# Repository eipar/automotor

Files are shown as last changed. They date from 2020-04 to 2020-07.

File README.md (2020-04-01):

# automotor
\simple Car's Radiator Driver Control

This is a project for the elective subject "Electronics in the Automotive" of the Electronic Engineering Degree at Universidad Tecnológica Nacional Facultad Regional Buenos Aires (UTN-FRBA).

The purpose of the code is to control the radiator of a car, according to the its temperature. This is done with fuzzy logic in a 8051 8-bit microcontroller.
The temperature and any other alarms is communicated through LIN and CAN protocol, this is done with a LPC1769 Stick.

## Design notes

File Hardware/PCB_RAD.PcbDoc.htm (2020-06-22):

Reporting Options

# File in Previous Format

Date | : | 27/04/2020
Time | : | 20:16:34
Filename | : | C:\Users\Euge\Documents\GitHub\automotor\Hardware\PCB_RAD.PcbDoc

Version | Warning

This file was generated by an earlier version of the software

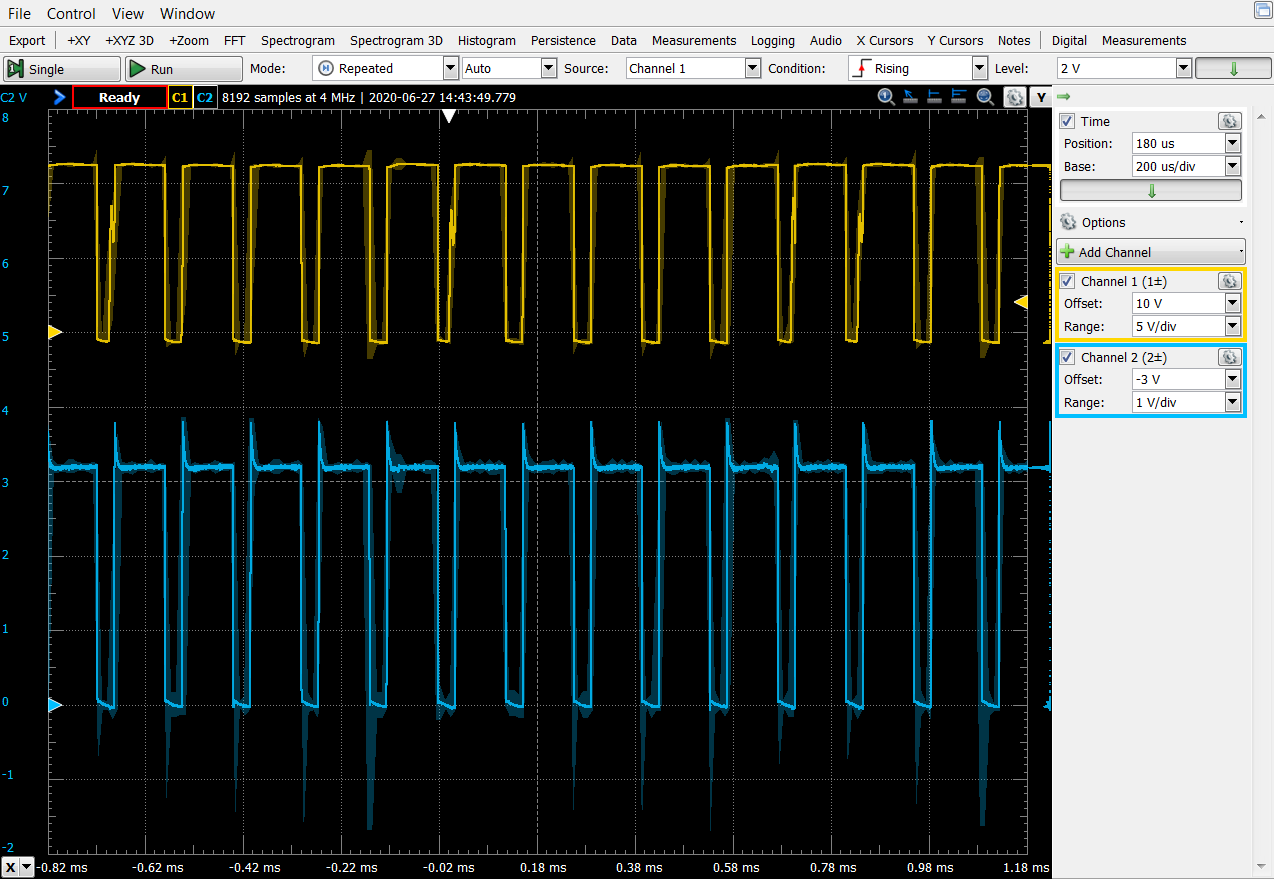
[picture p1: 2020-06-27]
Documentation/Motor/V_PWM.png

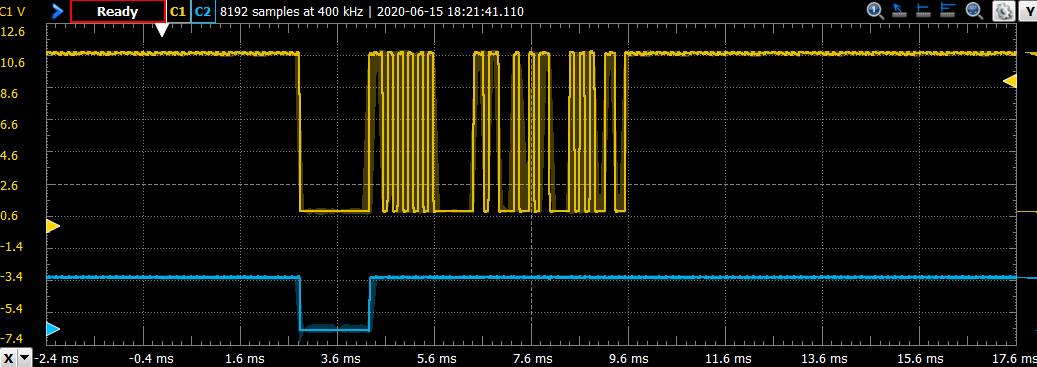
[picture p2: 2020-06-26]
Documentation/LIN/lin_write.png

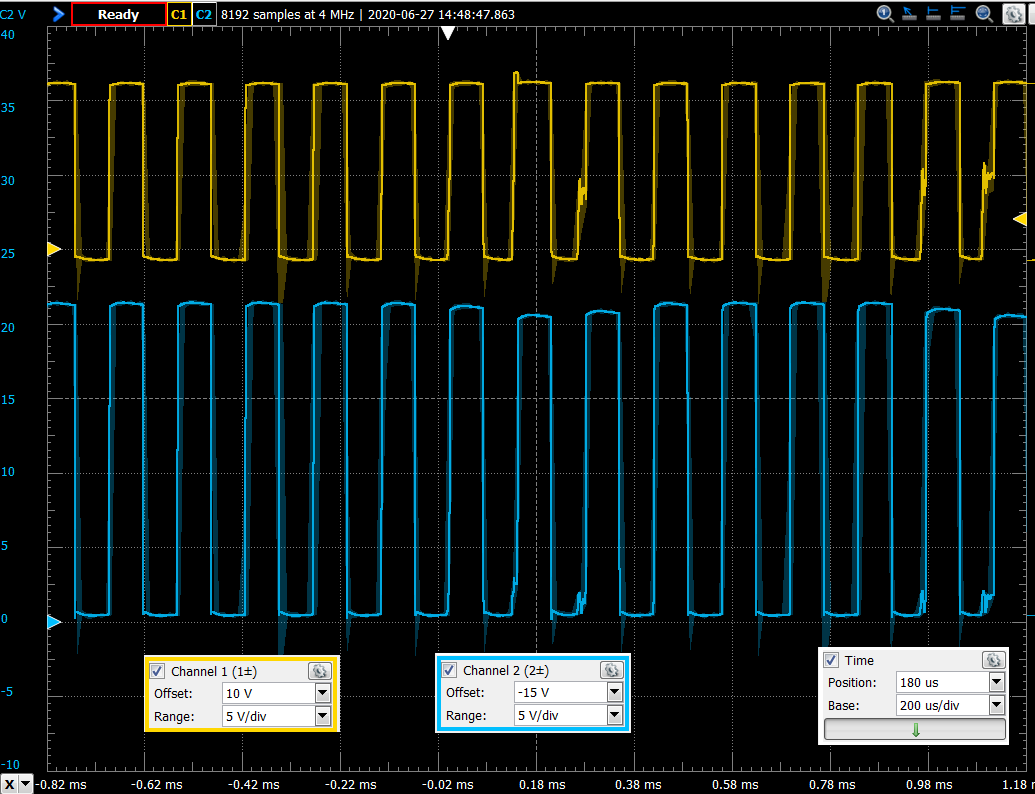
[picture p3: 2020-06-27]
Documentation/Motor_Modified/V_DC_Motor_y_Bootstrap.png

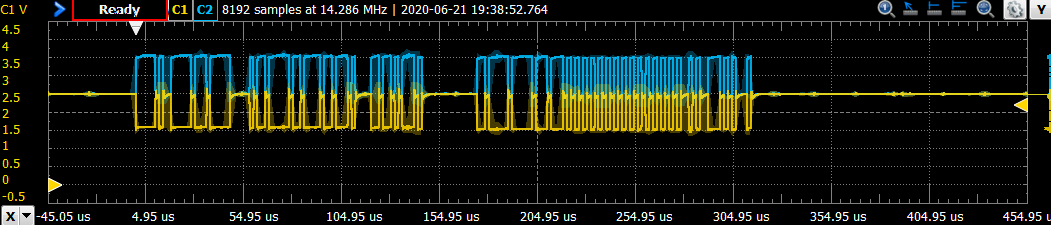
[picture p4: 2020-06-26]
Documentation/CAN/can_send_diag.png

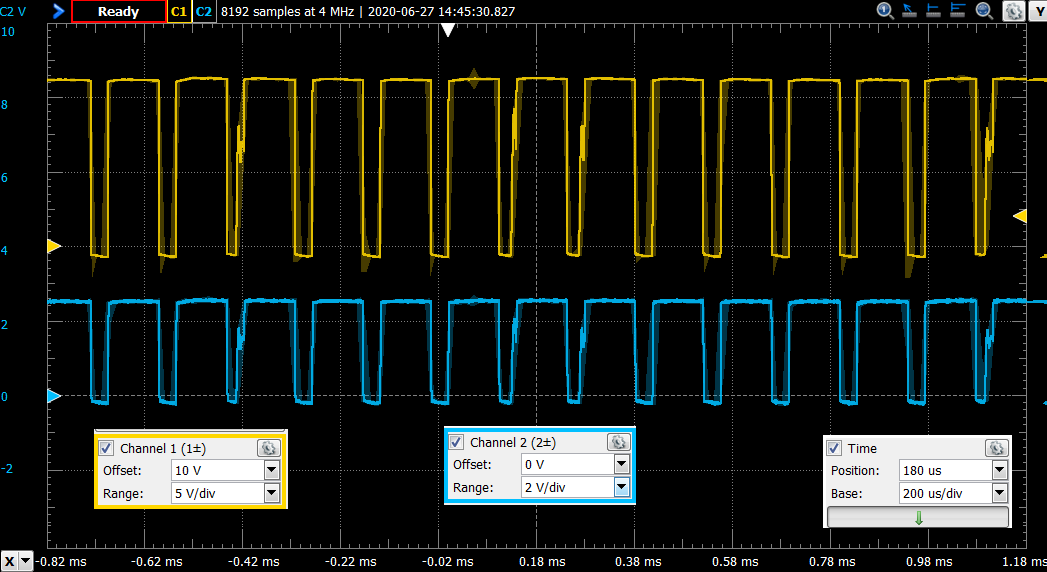
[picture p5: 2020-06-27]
Documentation/Motor_Modified/V_DC_Motor_y_Feedback.png

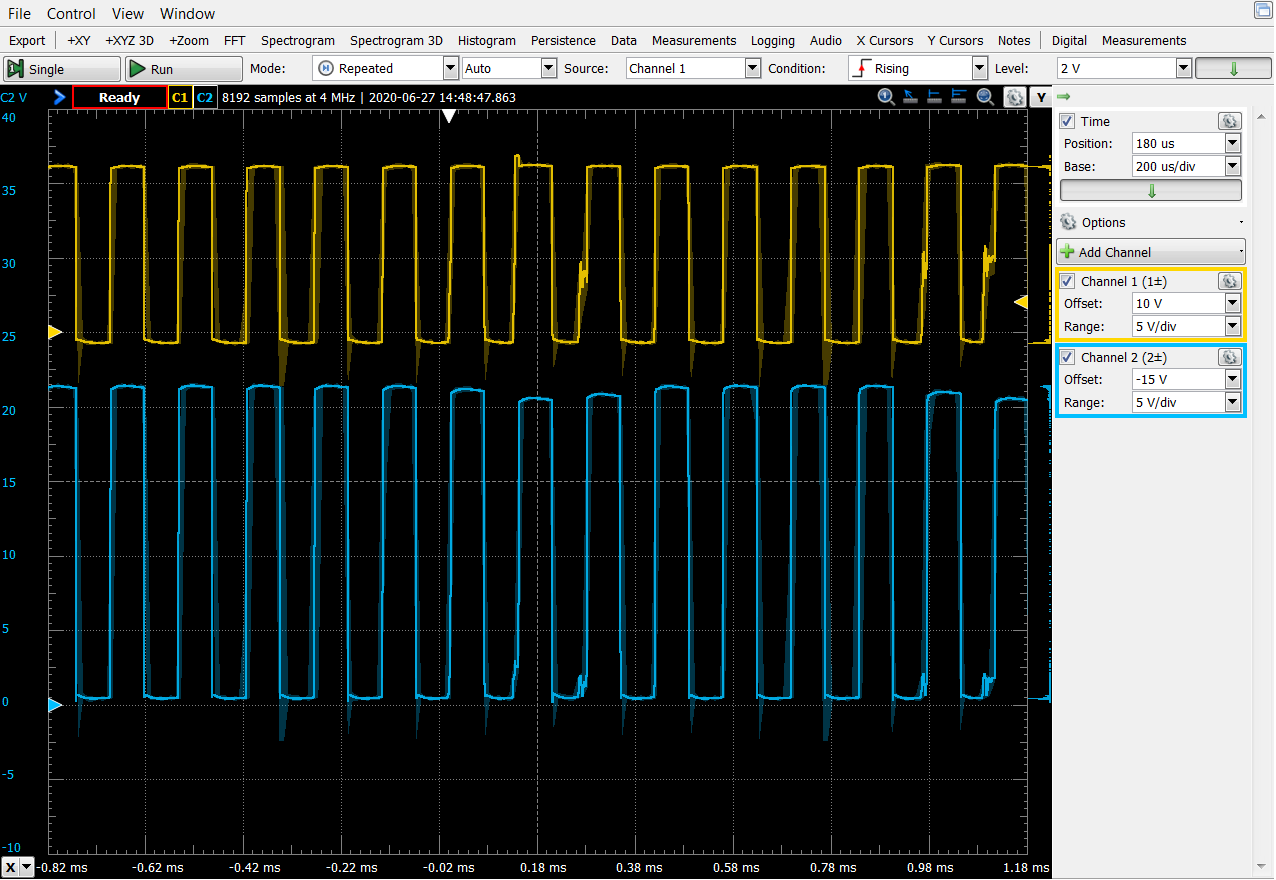
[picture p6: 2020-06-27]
Documentation/Motor/V_DC_Motor_y_Bootstrap.png

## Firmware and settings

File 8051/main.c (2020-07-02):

#define		APLICACION
#include	<controlador.h>

volatile bit check_temp;
volatile bit check_fuzzy;
volatile bit check_motor_on;

volatile bit flag_msg;
volatile unsigned char Temp, Diag;
extern unsigned char flagTx;
extern unsigned char Rx_In;

volatile unsigned char Temp, Diag;

volatile unsigned char rx_ok, tx_ok;
volatile unsigned int cant_flancos;

void main ( void )
{
	float temp_med;
	unsigned char  temp_fuzzy_in;
	unsigned int temp_fuzzy_int, temp_expanded;
	unsigned int cant_flancos_prev;

	PLACA_Init( );

	freno_OFF;
	
	EA = 1;	 // activo las interrupciones

	input[0] =0x00;
	input[1] = 0x3B;

   	Diag = 0xAA;

	AVISO_ON;
	LIN_CS_ON;
	LIN_WK_ON;
	
	while( 1 )
	{
		//test de si esto esta vivo o no
		//check_board_live();

		if(check_temp)
		{
			check_temp = 0;
			temp_med = LeerTemp( );
			check_status_sensor( temp_med );

			temp_fuzzy_in = (unsigned char) (temp_med + 50);
			if (temp_fuzzy_in >= 175) temp_fuzzy_in = 174;
			if (temp_fuzzy_in <  6  ) temp_fuzzy_in = 6; 
			Temp = temp_fuzzy_in;
			temp_fuzzy_int = (unsigned int)temp_fuzzy_in;
			temp_expanded = (temp_fuzzy_int*255/170)-8;
			input[0] = (unsigned char)(temp_expanded);
			temp_fuzzy_in = 0;
		}

		if(check_fuzzy)
		{
		 	check_fuzzy = 0;
			//P2 = input[1];
			fuzzy_engine();
			PCA0CPH0 = fuzzy_out[0];
			
		}

		if(flag_msg == 1)
		{
		 	flag_msg = 0;
			Mensajes();
		}

		if(check_motor_on == 1)
		{
		 	check_motor_on = 0;
			if (cant_flancos_prev == cant_flancos)
			{
				//significa que no hubo transiciones
				Diag = 0x66;
			}
			cant_flancos_prev = cant_flancos;
		}

	}
}

void count_int0 ( void ) interrupt 0
{
	cant_flancos++;
}

void timertick ( void ) interrupt 1
{
	static unsigned int ticks_sensor = 200;
	static unsigned int ticks_pwm = 100;
	static unsigned int ticks_int0 = 300;

	reset_system_timer ();

	ticks_sensor--;
	ticks_pwm--;
	ticks_int0--;

	if( !ticks_sensor )
	{	
		check_temp = 1;
		ticks_sensor = 1000;
	}		 

	if( !ticks_pwm ){
		ticks_pwm = 100;
		check_fuzzy = 1;
	}

	if( !ticks_int0){
		ticks_int0 = 5000;
		check_motor_on = 1;
	}
}

void pca0_handler (void) interrupt 9 
{
	unsigned char count_pos_low, count_pos_high;
	unsigned int total_time;

	CCF1 = 0; //bajo el flag de interrupcion

	if ((PCA0CPM1 & 0x10)) //esta configurado en neg edge
	{     //fue neg edge
		  PCA0L     = 0x00;	 //lo reseteo, no me interesa su valor actual
          PCA0H     = 0x00;
		  PCA_ON_POSEDGE; //PCA0CPM1  = 0x21; //pasar a interrupcion a pos edge
		  AVISO_OFF;
	}else{	  //fue interrupcion de pos edge
		  count_pos_low  = PCA0CPL1;
		  count_pos_high = PCA0CPH1;
		  total_time = (count_pos_high << 8) + count_pos_low;
		  if (total_time > TIME_13BITS) //cuenta llego al valor minimo?
		  {		
				//PCA_INT_OFF; //EIE1 = EIE1 & 0xF7;//desactivar la interrupcion del modulo
				//prendo la uart
		  		SCON1 = SCON1 | 0x10;  //prendo el bit 4, recepcion habilitada
				led4_OFF;
				AVISO_ON;
		  } else {
		  		AVISO_ON;
				led4_ON;
		  }
		  PCA_INT_OFF;
	}

}

void uart1_handler (void) interrupt 20
{
	unsigned char dato;
	int dato1;
	unsigned char checksum;

	//MaqEst para decodificar
	static char estado = ESPERA;
	static unsigned char Rx_count;

	if ( RX )
	{
		APAGAR_RX;
		dato = BUFER_RX_TX;
		if  (dato == 0x55 && estado == ESPERA)
		{ 
			estado = SYNC_BREAK_OK;
		}
		else if (estado == SYNC_BREAK_OK)
		{
			if (dato == ID_REC_DATA)
			{
				estado = REC_DATA; //me van a mandar el dato
			}
			else if (dato == ID_SEND_DATA)
			{
				//estado = ESPERA; //tengo que mandar yo el dato y terminar
				PushTx(Temp);
				PushTx(Diag);
				checksum = ~(Temp+Diag);
				PushTx(checksum);
				SCON1 = SCON1 & 0xEF;  //apago el bit 4, recepcion deshabilitada
				T2CON     = 0x04; 	   //prendo el timer 2
				ET2 = 1;		  	   //prendo su interrupcion
			}
			else
			{
				estado = ESPERA; //NO_ID;	//no es para mi
				//volver a activar el edge detector
				CCF1 = 0; //bajo el flag de interrupcion
				PCA_ON_NEGEDGE; //configuro el pca en neg edge
				PCA_INT_ON;		//prendo su interrupcion
				SCON1 = SCON1 & 0xEF;  //apago el bit 4, recepcion deshabilitada
			}	
		}
		else if (estado == REC_DATA)
		{
			PushRx(dato);
			Rx_count++;
			if (Rx_count == MAX_REC_BYTES)
			{
				Rx_count = 0x00;
				flag_msg = 1;
				estado = ESPERA;
				//volver a activar el edge detector
				CCF1 = 0; //bajo el flag de interrupcion
				PCA_ON_NEGEDGE; //configuro el pca en neg edge
				PCA_INT_ON;		//prendo su interrupcion
				SCON1 = SCON1 & 0xEF;  //apago el bit 4, recepcion deshabilitada
				rx_ok++;
			}
		}
	}

	if (TX)
	{
		APAGAR_TX;
		dato1 = PopTx();
		if ( dato1 != -1 )
		{
			BUFER_RX_TX	=  (unsigned char)dato1;
		}
		else
		{
			flagTx = 0;
			estado = ESPERA;
			CCF1 = 0; //bajo el flag de interrupcion
			PCA_ON_NEGEDGE;  //configuro el pca en neg edge
			PCA_INT_ON;      //prendo su interrupcion
		    SCON1 = SCON1 & 0xEF;  //apago el bit 4, recepcion deshabilitada
			tx_ok++;
		}
	}
}

void timer2_handler (void) interrupt 5
{
	// esto es para el tiempo que tiene que pasar entre ID y dato
	TF2 	  = 0;    //bajo el flag de interrupcion
	T2CON     = 0x00; //apago el timer 2
	ET2 = 0;		  //apago su interrupcion
	if ( !flagTx ) //si no esta prendido el transmisor, lo prendo
	{
		flagTx = 1;	
		ARRANCAR_TX;
	}
}

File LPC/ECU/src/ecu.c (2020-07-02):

/*
===============================================================================
 Name        : ecu.c
 Author      : $(author)
 Version     :
 Copyright   : $(copyright)
 Description : main definition
===============================================================================
*/

#if defined (__USE_LPCOPEN)
#if defined(NO_BOARD_LIB)
#include "chip.h"
#else
#include "board.h"
#endif
#endif

#include <cr_section_macros.h>

// TODO: insert other include files here
#include "ecu.h"

// TODO: insert other definitions and declarations here
volatile int led_flag;
volatile int send_uart_flag;
volatile int lin_master_ask_moment;
volatile int lin_master_write_moment;
volatile int rx_fifo_full;
volatile uint8_t zero_long_sent;

volatile uint8_t lin_acc;
volatile uint8_t flag_env_diag, flag_transmit_ready, flag_env_acc;
volatile uint8_t can_acc;

int main(void) {

	CAN_BUFFER_ID_T   TxBuf;
	CAN_MSG_T SendMsgBuf;
	uint8_t lin_temp_asked, lin_diag_asked;

    // Read clock settings and update SystemCoreClock variable
    SystemCoreClockUpdate();
    // Set up and initialize all required blocks and
    // functions related to the board hardware
    Board_Init();
    // Set the LED to the state of "On"
    Board_LED_Set(0, true);


    // TODO: insert code here
    int8_t data_received[CANT_DATOS];


    Set_Systick(INTS_PER_SECOND);

    Set_UART0_LIN();
    TIMER0_Init();

    lin_state_machine_ask 	= LIN_START;
    lin_state_machine_write = LIN_START;

    lin_acc = 0;

    CAN_Init();

	//CAN send alive
	SendMsgBuf.ID = CAN_TX_MSG_STD_ID;
	SendMsgBuf.DLC = 4;
	SendMsgBuf.Type = 0;
	SendMsgBuf.Data[0] = 'H';
	SendMsgBuf.Data[1] = 'O';
	SendMsgBuf.Data[2] = 'L';
	SendMsgBuf.Data[3] = 'A';
	TxBuf = CAN_BUFFER_1;
	Chip_CAN_Send(LPC_CAN, TxBuf, &SendMsgBuf);

    while(1) {

        if(led_flag) //just a keep alive check
        {
        	led_flag = 0;
        	Board_LED_Toggle(0);
        }

    	if(flag_env_diag & flag_transmit_ready)
    	{
    		//enviar diagnostico via CAN
    		//reenviar lo que envia LIN
    		flag_env_diag = 0;
    		flag_transmit_ready = 0;
    		SendMsgBuf.Data[0] = lin_temp_asked;
    		SendMsgBuf.Data[1] = lin_diag_asked;
    		SendMsgBuf.Data[2] = 0x55;
    		SendMsgBuf.Data[3] = 0xAA;
    		Chip_CAN_Send(LPC_CAN, TxBuf, &SendMsgBuf);
    	}

    	if(flag_env_acc)
    	{
    		//mandar la aceleracion por LIN
    		lin_acc = can_acc;
    		flag_env_acc = 0;
    	}

        //state machine for asking
        if(lin_master_ask_moment)
        {
        	//state machine for asking status to slave
        	if(lin_master_write_moment && lin_state_machine_write != LIN_START)
        	{
        		lin_state_machine_ask = LIN_START; //wait
        	}
        	else if(lin_state_machine_ask == LIN_START)
			{
				LIN_Send(C_LONG_ZERO);
				lin_state_machine_ask = LIN_SENDING_LONG;
			}
			else if(lin_state_machine_ask == LIN_SENDING_LONG)
			{
				//wait for long zero, think how, this is not uart standard
				if(zero_long_sent) //long zero is sent
				{
					lin_state_machine_ask = LIN_SEND_SYNC;
					zero_long_sent = 0;
					Chip_GPIO_SetPinOutHigh(LPC_GPIO, PORT_0, PIN_2_TXD0);
					for(int i=0;i<2000;i++);
					Chip_IOCON_PinMuxSet(LPC_IOCON, PORT_0, PIN_2_TXD0, IOCON_FUNC1);
					Chip_UART_TXEnable(UART_LIN);
				}
				else
				{
					lin_state_machine_ask = LIN_SENDING_LONG;
				}
			}
			else if(lin_state_machine_ask == LIN_SEND_SYNC)
			{
				LIN_Send(C_SYNC_BREAK);
				lin_state_machine_ask = LIN_SEND_ID;
			}
			else if(lin_state_machine_ask == LIN_SEND_ID)
			{
				LIN_Send(C_SLAVE_ID_READ);
				lin_state_machine_ask = LIN_WAIT_DATA;
			}
			else if(lin_state_machine_ask == LIN_WAIT_DATA)
			{
				if(rx_fifo_full)
				{
					lin_state_machine_ask = LIN_PROCESS_DATA;
					rx_fifo_full = 0;
				}
				else
				{
					lin_state_machine_ask = LIN_WAIT_DATA;
				}
			}
			else if(lin_state_machine_ask == LIN_PROCESS_DATA)
			{
				for(int i=0;i<CANT_DATOS;i++)
				{
					data_received[i] = PopRx();
				}
				if((data_received[SYNK_BREAK_INX] == SYNC_BREAK) && (data_received[SLAVE_ID_INX] == (int8_t)SLAVE_ID_READ))
				{	//my transmission was right
					//process data here...
					if(check_checksum(data_received[3],data_received[4],data_received[5]))
					{	//if data is ok
						lin_master_ask_moment = 0;
						lin_temp_asked = data_received[3];
						lin_diag_asked = data_received[4];
						if(lin_diag_asked == 0x66)
						{
							Chip_GPIO_SetPinOutHigh(LPC_GPIO, LIN_LED_ALARM_PORT, LIN_LED_1_PIN);
						}
					}
					else
					{	//data is wrong, restart
						lin_master_ask_moment = 1;
						Chip_GPIO_SetPinOutHigh(LPC_GPIO, LIN_LED_ALARM_PORT, LIN_LED_2_PIN);
					}
				}
				else
				{	//my transmission was wrong
					lin_master_ask_moment = 1;
				}
				lin_state_machine_ask = LIN_START; //start again
			}
       	}
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

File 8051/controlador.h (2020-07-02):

#ifndef		CONTROLADOR_H
#define		CONTROLADOR_H

//===============================================================================================
// CONTROLADOR DE MOTOR DE DC EN FUNCION DE LA TEMPERATURA DEL LIQUIDO REFRIGERANTE
//===============================================================================================
//-----------------------------------------------------------------------------------------------
// Includes
//-----------------------------------------------------------------------------------------------
#ifdef		C8051F020
#include	<C8051F020.h>
#endif

#include	<ntcm12.h>		    	// Sensor de temperatura
#include	<fuzzy.h>

#include	<stdio.h>
#include	<stdlib.h>
#include	<string.h>
#include	<intrins.h>
//-----------------------------------------------------------------------------------------------
// Defines
//-----------------------------------------------------------------------------------------------
#define 	ACTIVO_ALTO			0x01
#define 	ACTIVO_BAJO			0x00
#define 	ON					0x01
#define		OFF					0x00
#define		HIGH				0x01
#define		LOW					0x00
#define		TEMPERATURA			0
#define		HUMEDAD				1
#define		PRESION				2
#define		SENSOR_TEMPERATURA	0x9E
//-----------------------------------------------------------------------------------------------
// Macros
//-----------------------------------------------------------------------------------------------
// Macros para setear, limpiar y pullear bits en particular de puertos
#define		setbitp( puerto,pin,activo ) \
								(( puerto ) = ((( activo ) == ACTIVO_ALTO) ? \
								(( puerto ) | (0x01 << ( pin ))) : \
								(( puerto ) & ~(0x01 << ( pin )))))
#define		clrbitp( puerto,pin,activo ) \
								(( puerto ) = ((( activo ) == ACTIVO_BAJO) ? \
								(( puerto ) | (0x01 << ( pin ))) : \
								(( puerto ) & ~(0x01 << ( pin )))))
#define		ifpinp( puerto,pin,estado ) \
								((((( puerto ) >> ( pin )) & 0x01) == \
								( estado )) ? ON : OFF)

//Macros varias para los 4 leds	del kit de desarrollo
#define		led1_ON			setbitp( P5, 4, ACTIVO_ALTO )
#define		led1_OFF		clrbitp( P5, 4, ACTIVO_ALTO )
#define		led1_STATUS		ifpinp ( P5, 4, ACTIVO_ALTO )
#define     led2_ON			setbitp( P5, 5, ACTIVO_ALTO )
#define     led2_OFF		clrbitp( P5, 5, ACTIVO_ALTO )
#define		led3_ON			setbitp( P5, 6, ACTIVO_ALTO )
#define		led3_OFF		clrbitp( P5, 6, ACTIVO_ALTO )
#define		led4_ON			setbitp( P5, 7, ACTIVO_ALTO )
#define		led4_OFF		clrbitp( P5, 7, ACTIVO_ALTO )
#define		led4_STATUS		ifpinp ( P5, 7, ACTIVO_ALTO )

//Macros para saber el estado de los botonoes
#define		tact0_STATUS		ifpinp( P5, 0, ACTIVO_BAJO )
#define		tact1_STATUS		ifpinp( P5, 1, ACTIVO_BAJO )
#define		tact2_STATUS		ifpinp( P5, 2, ACTIVO_BAJO )
#define		tact3_STATUS		ifpinp( P5, 3, ACTIVO_BAJO )

//Macros para frenar el motor
#define 	freno_OFF		setbitp( P1, 0, ACTIVO_ALTO )
#define		freno_ON		clrbitp( P1, 0, ACTIVO_ALTO )

//Macros para manejar el PWM
#define		PWM_ENABLE		(PCA0CN    = 0x40)
#define 	PWM_DISABLE		(PCA0CN    = 0x00)
#define		PMW_0_DUTY		(PCA0CPM0 = PCA0CPM0 & 0xBF)
#define		PWM_ON			(PCA0CPM0 = PCA0CPM0 | 0x42)
#define		PWM_UP			(PCA0CPH0--)
#define		PWM_SPEED_UP	(PCA0CPH0--)
#define		PWM_SPEED_DOWN	(PCA0CPH0++)
#define		PWM_DOWN		(PCA0CPH0++)
#define		PWM_VAL_INI		(PCA0CPH0  = 0x10)
#define		PWM_MAX_STATUS	(PCA0CPH0  == 0xE6)
//#define		PWM_PIN_0		(clrbitp(P0, 2, ACTIVO_ALTO))

//Define para el PCA0
#define 	TIME_13BITS		2400 //1300 //2500
#define		PCA_ON_POSEDGE	(PCA0CPM1  = 0x21)
#define		PCA_ON_NEGEDGE 	(PCA0CPM1  = 0x11)
#define		PCA_INT_ON		(EIE1 = EIE1 | 0x08)
#define		PCA_INT_OFF		(EIE1 = EIE1 & 0xF7)

//Macros para la UART
#define ARRANCAR_TX		(SCON1 = SCON1 | 0x02)
#define TX				(SCON1 & 0x02)
#define RX				(SCON1 & 0x01)
#define APAGAR_TX		(SCON1 = SCON1 & 0xFD )
#define APAGAR_RX		(SCON1 = SCON1 & 0xFE )
#define BUFER_RX_TX		SBUF1

#define ESPERA			0
#define	SYNC_BREAK_OK	1
#define	REC_DATA		2
#define	SEND_DATA		3
//Necesito recibir el estado de aceleracion, con un byte me alcanza
//Necesito transmitir la temperatura y algun coso de diagnostico, 2 bytes
//entonces puedo usar los ID 0 y 1
//que con los bits de paridad se convierten en:
#define ID_REC_DATA		0x80
#define ID_SEND_DATA	0xC1
//segun la norma

#define MAX_REC_BYTES	3

#define AVISO_ON	setbitp( P0, 6, ACTIVO_ALTO)
#define AVISO_OFF	clrbitp( P0, 6, ACTIVO_ALTO)
#define	LIN_CS_ON	setbitp( P1, 2, ACTIVO_ALTO)		
#define	LIN_CS_OFF	clrbitp( P1, 2, ACTIVO_ALTO)
#define	LIN_WK_ON	setbitp( P1, 4, ACTIVO_ALTO)		
#define	LIN_WK_OFF	clrbitp( P1, 4, ACTIVO_ALTO)


//-----------------------------------------------------------------------------------------------
// Prototipos de funciones
//-----------------------------------------------------------------------------------------------
void		delay				( unsigned int tiempo );
void		PLACA_Init	    	( void );

void 		reset_system_timer  ( void );
void 		check_status_sensor ( float );
void 		check_board_live 	( void );

void 		fuzzy_engine(void);
unsigned char compute_memval(unsigned char,unsigned char );
void defuzzify(void);
void normalize (void);

void PushTx(unsigned char );
void PushRx(unsigned char );
int PopRx (void);
int PopTx (void);
void Transmitir( char *);
void Mensajes (void );
unsigned char calculate_checksum( unsigned char, unsigned char );
//===============================================================================================
//-----------------------------------------------------------------------------------------------
// Globales
//-----------------------------------------------------------------------------------------------
#ifdef		APLICACION
	data volatile float temperatura_medida = 0;
#endif
//-----------------------------------------------------------------------------------------------
// Prototipos de funciones
//-----------------------------------------------------------------------------------------------

//===============================================================================================

#endif		/* EMA_H */

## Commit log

2020-04-01 gitignores y Carpetas
    Agregué un gitignore en todas las carpetas, no sólo para usarlo sino para que cree las tarjetas
2020-04-01 First upload
    Simulation, the PCB docs and some documentation are uploades
    [8051_SCH.SchDoc, CAN_SCH.SchDoc, Controlador_SCH.SchDoc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]
2020-04-02 First code for 8051
    The source files of current test. This include motor control with buttons, and a simulation of the temp sensor with the potentiometer present in the development kit.
2020-04-02 Models upload
    Models for simulation of current sensor added
2020-04-05 Added fuzzy rules
    One xls file with the rules of the fuzzy engine is added to the project
    [Fuzzy Table.xlsx]
2020-04-05 Updated tables
    New tables
    [Fuzzy Table.xlsx]
2020-04-05 First version of mu graphics
    The firts graphics with the mu functions are added
    [Fuzzy Table.xlsx]
2020-04-06 First fuuzy code
    First version of fuzzy code. Compilation still unsuccesful
    [Fuzzy Table.xlsx]
2020-04-07 Fuzzy code up
    The code is in a first version. it does not work yet
    [Fuzzy Table.xlsx]
2020-04-08 Fuzzy code upgraded
    The fuzzy code works, but there is a problem with the fuzzzyfication of the inputs
    [fuzzy.c, main.c]
2020-04-10 Fuzzy engine working
    The 8051-part works as a controller. The acceleration input is simulated with the systick for the moment. Still no feedback from the DC motor
    [Fuzzy Table.xlsx]
2020-04-10 Last version of tables
    I forgot to commit the new tables with the offset to make the temperature a natural value...
    [Fuzzy Table.xlsx]
2020-04-20 LIN project started
    Sub project for 8051 to implement LIN protocol uploaded to repo
    [RAD.PrjPcb]
2020-04-20 LIN 13bits low detector working
    The first version of the LIN start detector is working. Next step is to implement UART after that
2020-04-23 LIN Slave working
    LIN slave seems to wirk. First test were conducted and passed
2020-04-25 BLocking delay in LIN
    Bugs corrections in LIN transmitter. If the transmission started too soon, the MCP2003A behaves weird, so a delay was added. Next step is to avoid blocking delay
    [controlador.h, inicializar.c, main.c]
2020-04-27 Code to test current measurement
2020-06-08 Some LIN code
    First LIN code with LPC Open ready. Uart is working, not according to expectations
2020-06-27 measures on motor
2020-06-29 Improvements in motor control
    The problem of no-zero-pwm was corrected
    [fuzzy.c]
2020-07-02 Misc improvements
    Leds where configured, P2 of 8051 added to report Acceleration received, diagnostic based on toogles of high power PWM added. Fuzzy trapezoids corrected. Excel now calculates slope points
    [Fuzzy Table.xlsx]
2020-07-02 Ready for final exam
    Everything ready for the final, so we are in THE FINAL COUNTDOWN
    [Fuzzy Table.xlsx]
